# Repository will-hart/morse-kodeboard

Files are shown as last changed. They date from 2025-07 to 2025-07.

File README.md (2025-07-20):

# Morse Kodeboard

I can type 1,250 words per minute on a keyboard with only the minor side effects
of deafening people within 50 meters and wearing out the delete key inside a week.
It occurs to me that If a TKL keyboard makes me 82.24563x more of an engineer,
then how much more engineer would you become by removing 86 of the other keys?

Of course disruption requires innovation, and clearly you can't be a 1,000,000x
engineer with just an "a" key. I considered using an LLM to interpret my intentions
from the velocity and anger with which the key was pressed, but then after a
period of quiet reflection I realised training an AI to do this would immediately
make it sentient.

So to save all of humanity from an AI overlord, I instead applied my vast and
terrifying engineering skills to come up with something the likes of which
has never been seen before. This technological marvel is both simple and truly
disruptive. I invented the idea of using a sequence of long and short pulses to
represent the characters I want to type. I decided to call it a "Morse" coding
sequence, named after [Inspector Morse](https://www.imdb.com/title/tt0092379/)
because I once lived somewhere where an episode was filmed.

This new type of keyboard is clearly more than a keyboard, as without it being
a 1,000,000x engineer clearly isn't possible. So in honor of the great Inspector,
I will call this marvel of modern science a

> **Morse Kodeboard**.

## TLDR

Somehow somebody thought of this idea and I though it would be fun. This is (rust)
firmware for a RP Pico that uses a ~single button~ three buttons and morse code
and pretends to be a USB HID keyboard. Technically it doesn't have a delete button
so good luck if you morse code wrong, which is highly likely because I don't even
know morse code.

## License

* Software: MIT or Apache 2.0
* Hardware: CERN Open Hardware 2.0 - Permissive

## Things I (re/)learned while doing this

- USB Descriptors are always a pain, but I guess with embassy its kind of straightforward?
- Most embassy examples don't use tasks for USB. Its because the code is messier
  as you need to make a lot of the descriptor buffers etc `static`. Using
  `StaticCell` was pretty handy here (there was one embassy example).
- Wireshark + USBpcap are your friend! (although its still tricky working out which
  interface you're meant to look at in Windows).
  - Filter messages to a specific address using `usb.addr[0:4] == "1.1."`
- Make sure to throttle loops, this was the cause of the keyboard not being recognised
  as the USB listening loop was running without any throttling.

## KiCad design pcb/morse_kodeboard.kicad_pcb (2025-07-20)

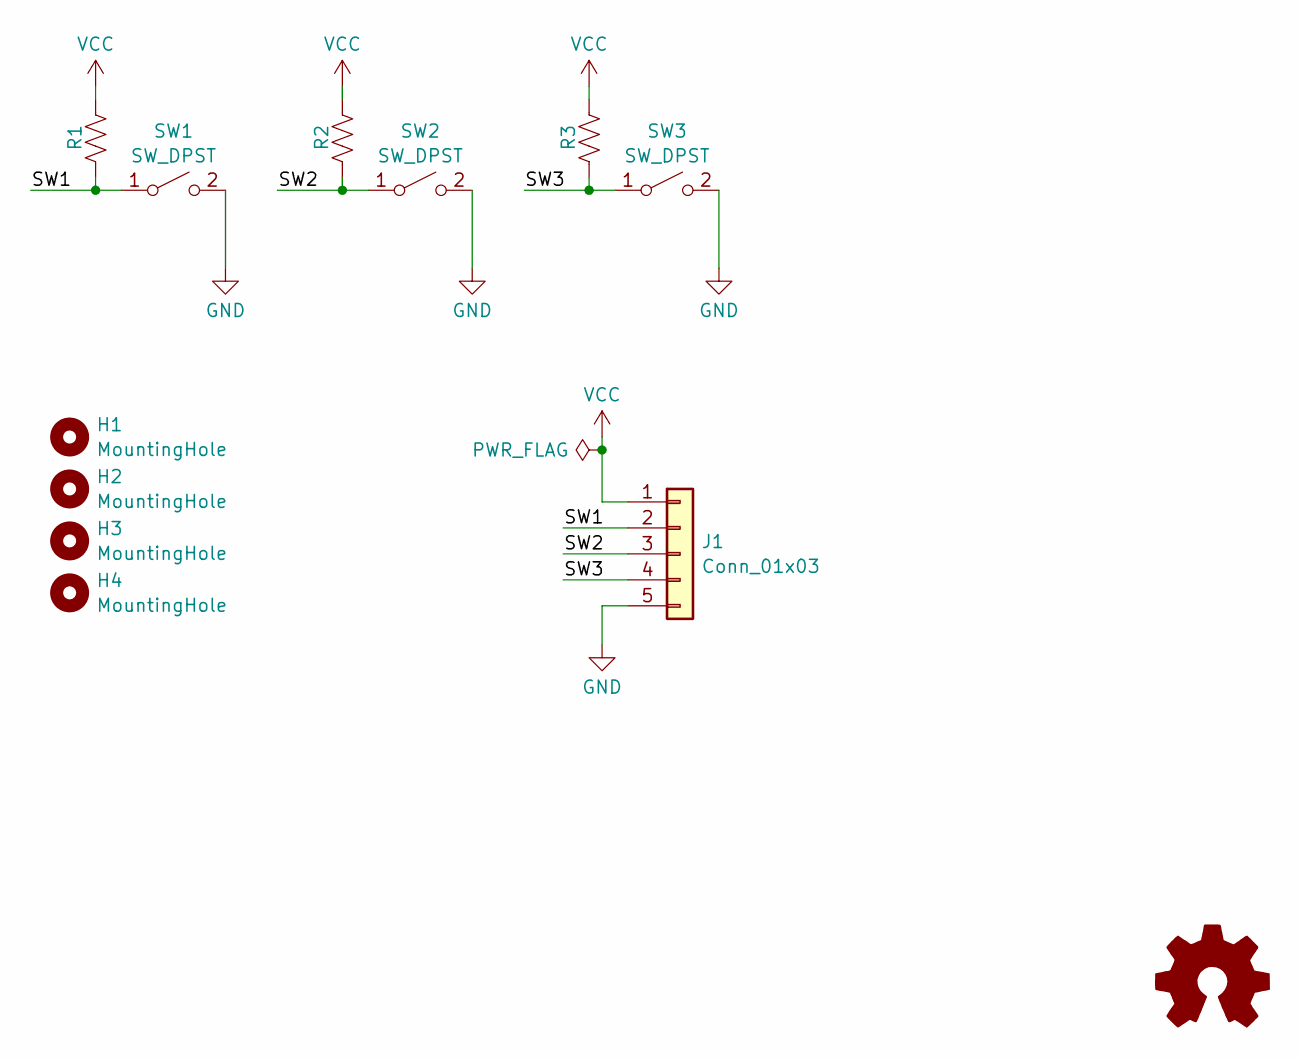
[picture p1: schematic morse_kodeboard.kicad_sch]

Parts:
H1, H2, H3, H4: MountingHole; MountingHole_2.2mm_M2
J1: Conn_01x03; JST_PH_S5B-PH-K_1x05_P2.00mm_Horizontal
R1, R2, R3: R_US; R_0805_2012Metric_Pad1.20x1.40mm_HandSolder
SW1, SW2, SW3: SW_DPST; SW_Hotswap_Kailh_MX_1.00u
SYM1: Logo_Open_Hardware_Small; OSHW-Logo2_7.3x6mm_Copper

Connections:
/SW1: J1.2, R1.2, SW1.1 (A)
/SW2: J1.3, R2.2, SW2.1 (A)
/SW3: J1.4, R3.2, SW3.1 (A)
GND: J1.5, SW1.2 (B), SW2.2 (B), SW3.2 (B)
VCC: J1.1, R1.1, R2.1, R3.1

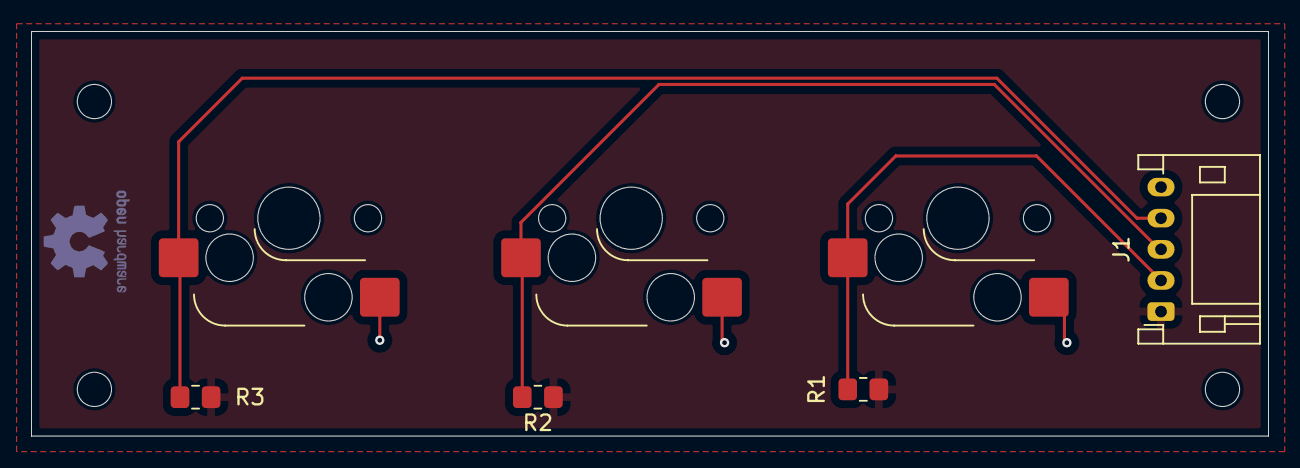
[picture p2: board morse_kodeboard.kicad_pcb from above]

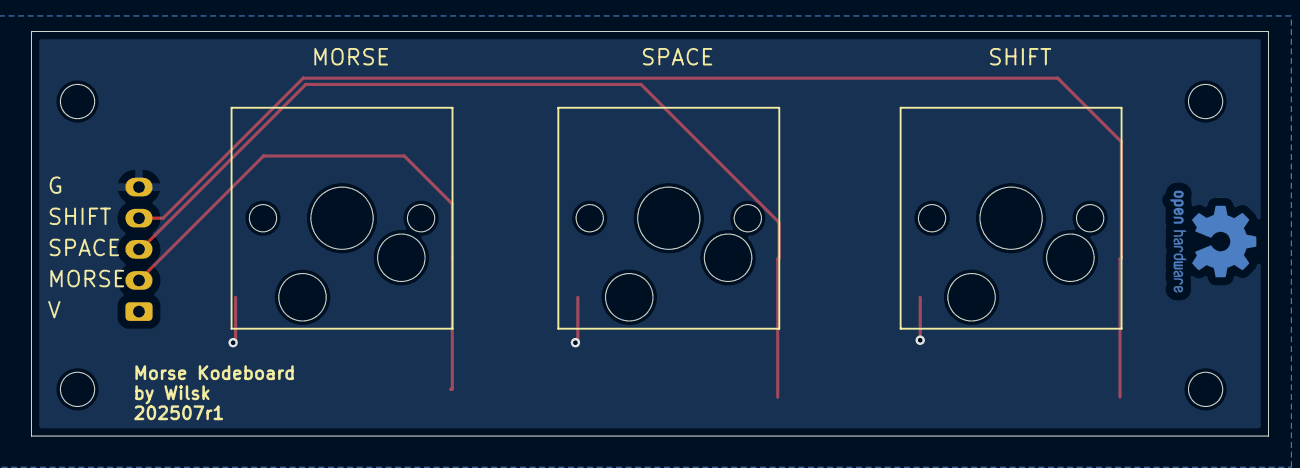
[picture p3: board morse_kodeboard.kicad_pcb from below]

Board: 2 copper layers, 79.5 x 26.0 mm, 12 parts (4 on the bottom side), 5 nets.

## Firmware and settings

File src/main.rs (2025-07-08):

#![no_std]
#![no_main]

use defmt::*;
use embassy_executor::Spawner;
use embassy_rp::bind_interrupts;
use embassy_rp::gpio::{Input, Pull};
use embassy_rp::peripherals::USB;
use embassy_rp::usb::{Driver, InterruptHandler};
use embassy_sync::blocking_mutex::raw::ThreadModeRawMutex;
use embassy_sync::channel::{Channel, Receiver, Sender};
use embassy_sync::mutex::Mutex;
use embassy_time::{Duration, Instant, Ticker, Timer};
use embassy_usb::class::hid::{HidReader, HidReaderWriter, HidWriter, State};
use embassy_usb::msos::windows_version;
use embassy_usb::{Builder, Config, UsbDevice};
use key_mapping::char_to_hid_u8;
use static_cell::StaticCell;
use usb::KodeboardUsbDeviceHandler;
use usbd_hid::descriptor::{KeyboardReport, SerializedDescriptor};
use {defmt_rtt as _, panic_probe as _};

mod debouncer;
mod decoder;
mod key_mapping;
mod usb;

bind_interrupts!(struct Irqs {
    USBCTRL_IRQ => InterruptHandler<USB>;
});

type EventChannelType = (char, bool);
type EventChannel = Channel<ThreadModeRawMutex, EventChannelType, 32>;
type EventSender = Sender<'static, ThreadModeRawMutex, EventChannelType, 32>;
type EventReceiver = Receiver<'static, ThreadModeRawMutex, EventChannelType, 32>;
static EVENT_CHANNEL: EventChannel = Channel::new();

// Descriptors for the USB. Static so we can share the USB handles around tasks
static CONFIG_DESC: StaticCell<[u8; 256]> = StaticCell::new();
static BOS_DESC: StaticCell<[u8; 256]> = StaticCell::new();
static MSOS_DESC: StaticCell<[u8; 256]> = StaticCell::new();
static CONTROL_BUF: StaticCell<[u8; 64]> = StaticCell::new();

// The state for the USB
static STATE: StaticCell<State> = StaticCell::new();

// The USB device handler
static USB_DEV_HANDLER: StaticCell<KodeboardUsbDeviceHandler> = StaticCell::new();

type ButtonType = Mutex<ThreadModeRawMutex, Option<Input<'static>>>;
static MORSE_BUTTON: ButtonType = Mutex::new(None);
static SPACE_BUTTON: ButtonType = Mutex::new(None);
static SHIFT_BUTTON: ButtonType = Mutex::new(None);

macro_rules! setup_button {
    ($pin: expr, $target: expr) => {
        // Set up the button for listening to morse code inputs
        let mut btn = Input::new($pin, Pull::Up);
        btn.set_schmitt(true);
        {
            *($target.lock().await) = Some(btn);
        }
    };
}

macro_rules! read_button {
    ($btn: expr) => {{
        let btn_unlocked = $btn.lock().await;

        if let Some(btn_ref) = btn_unlocked.as_ref() {
            Some(btn_ref.is_high())
        } else {
            None
        }
    }};
}

#[embassy_executor::main]
async fn main(spawner: Spawner) {
    info!("Connected a Morse Kodeboard!");
    info!("Configuring...");

    let p = embassy_rp::init(Default::default());

    // Set up USB
    let driver = Driver::new(p.USB, Irqs);
    let device_handler = USB_DEV_HANDLER.init(usb::KodeboardUsbDeviceHandler::default());

    // TODO: this is a test code from pid.codes, change before release
    let mut config = Config::new(0x16c0, 0x27dd);
    config.manufacturer = Some("Wilsk");
    config.product = Some("Morse Kodeboard");
    config.serial_number = Some("000001");
    config.max_power = 100;
    config.max_packet_size_0 = 64;

    let mut builder = Builder::new(
        driver,
        config,
        &mut CONFIG_DESC.init([0; 256])[..],
        &mut BOS_DESC.init([0; 256])[..],
        &mut MSOS_DESC.init([0; 256])[..],
        &mut CONTROL_BUF.init([0; 64])[..],
    );
    builder.handler(device_handler);
    builder.msos_descriptor(windows_version::WIN10, 2);

    // Create the HID inteface
    let hid_config = embassy_usb::class::hid::Config {
        report_descriptor: KeyboardReport::desc(),
        request_handler: None,
        poll_ms: 60,
        max_packet_size: 64,
    };
    let hid = HidReaderWriter::<_, 1, 8>::new(&mut builder, STATE.init(State::new()), hid_config);
    let usb = builder.build();

    // Set up the button for listening to morse code inputs
    setup_button!(p.PIN_14, SPACE_BUTTON);
    setup_button!(p.PIN_15, SHIFT_BUTTON);
    setup_button!(p.PIN_16, MORSE_BUTTON);

    info!("Configuration complete");

    // Now start spinning up the tasks
    info!("Spawning USB handling task");
    unwrap!(spawner.spawn(usb_loop(usb)));

    info!("Spawning usb HID transmission task");
    let (reader, writer) = hid.split();
    unwrap!(spawner.spawn(usb_hid_loop(EVENT_CHANNEL.receiver(), writer)));

    info!("Spawning USB request handler task");
    unwrap!(spawner.spawn(usb_request_handler(reader)));

    info!("Spawning space bar monitoring task");
    unwrap!(spawner.spawn(monitor_space_key(&SPACE_BUTTON, EVENT_CHANNEL.sender())));

    info!("Spawning morse code button observer task");
    unwrap!(spawner.spawn(generate_morse_code_characters(
        &MORSE_BUTTON,
        &SHIFT_BUTTON,
        EVENT_CHANNEL.sender()
    )));
}

/// The underlying USB send/receive loop on the [UsbDevice]
#[embassy_executor::task]
async fn usb_loop(mut usb: UsbDevice<'static, Driver<'static, USB>>) -> ! {
    usb.run().await
}

/// Listens for events from the morse code parser and sends them on as key
/// presses on the HID keyboard interface
#[embassy_executor::task]
async fn usb_hid_loop(
    event_receiver: EventReceiver,
    mut writer: HidWriter<'static, Driver<'static, USB>, 8>,
) {
    info!("Starting event loop");
    // throttle the loop a little bit
    let mut ticker = Ticker::every(Duration::from_millis(20));
    loop {
        match event_receiver.try_receive() {
            Ok((char, shift_held)) => {
                let Some(code) = char_to_hid_u8(char) else {
                    continue;
                };

                info!(
                    "Sending '{}{}' Key ({}u8)",
                    if shift_held { "shift+" } else { "" },
                    char,
                    code
                );
                let report = KeyboardReport {
                    keycodes: [code, 0, 0, 0, 0, 0],
                    leds: 0,
                    modifier: if shift_held { 0x02 } else { 0 },
                    reserved: 0,
                };
                // Send the report.
                match writer.write_serialize(&report).await {
                    Ok(()) => {}
                    Err(e) => warn!("Failed to send report: {:?}", e),
                };

                // delay 10ms before we release the key
                Timer::after(Duration::from_millis(10)).await;

                info!("Releasing '{}' Key", char);
                let report = KeyboardReport {
                    keycodes: [0, 0, 0, 0, 0, 0],
                    leds: 0,
                    modifier: 0,
                    reserved: 0,
                };
                // Send the report.
                match writer.write_serialize(&report).await {
                    Ok(()) => {}
                    Err(e) => warn!("Failed to send report: {:?}", e),
                };
            }
            Err(_err) => {
                // nop - we just move on
            }
        }

        ticker.next().await;
    }
}

/// Handles USB requests received on the [`HidReader`]
#[embassy_executor::task]
async fn usb_request_handler(reader: HidReader<'static, Driver<'static, USB>, 1>) {
    let mut request_handler = usb::KodeboardUsbRequestHandler::default();
    reader.run(false, &mut request_handler).await;
}

/// Listens for the space key and then sends a "space" event to the keyboard
#[embassy_executor::task]
async fn monitor_space_key(space_btn: &'static ButtonType, sender: EventSender) {
    let mut ticker = Ticker::every(Duration::from_millis(5));
    let mut btn_debouncer = if let Some(btn_ref) = space_btn.lock().await.as_ref() {
        debouncer::DebouncedInput::new(btn_ref.is_high())
    } else {
        crate::panic!("Unable to access button")
    };

    let mut prev_high = btn_debouncer.current();

    loop {
        let result = {
            if let Some(btn) = read_button!(space_btn) {
                btn_debouncer.debounce(btn)
            } else {
                btn_debouncer.current()
            }
        };

        if result != prev_high {
            prev_high = result;

            if result {
                info!("Space button pressed");
                sender.send((' ', false)).await;
            }
        }

        ticker.next().await;
    }
}

/// Listens to the supplied button and passes button actions (press/release) to
/// a morse code decoder. As characters are received by the encoder it sends them
/// through the [`EventSender`] channel for transmission via USB HID.
#[embassy_executor::task]
async fn generate_morse_code_characters(
    morse_btn: &'static ButtonType,
    shift_btn: &'static ButtonType,
    sender: EventSender,
) {
    info!("Configuring morse decoder");
    let mut morse_decoder = decoder::Decoder::new(60);
    let mut ticker = Ticker::every(Duration::from_millis(1));

    let mut morse_debouncer = if let Some(btn_ref) = morse_btn.lock().await.as_ref() {
        debouncer::DebouncedInput::new(btn_ref.is_high())
    } else {
        crate::panic!("Unable to configure morse button")
    };

    let mut shift_debouncer = if let Some(btn_ref) = shift_btn.lock().await.as_ref() {
        debouncer::DebouncedInput::new(btn_ref.is_high())
    } else {
        crate::panic!("Unable to configure shift button")
    };
    let mut prev_shift_state = shift_debouncer.current();
    let mut shift_held = false;

    info!("Starting morse listen loop");
    loop {
        // debounce the input
        let morse_btn = if let Some(btn) = read_button!(morse_btn) {
            morse_debouncer.debounce(btn)
        } else {
            morse_debouncer.current()
        };

        let shift_button = if let Some(btn) = read_button!(shift_btn) {
            shift_debouncer.debounce(btn)
        } else {
            shift_debouncer.current()
        };

        if shift_button != prev_shift_state {
            prev_shift_state = shift_button;
            if shift_button {
                shift_held = !shift_held;
                info!("Toggled Shift to {}", shift_held);
            }
        }

        // update the morse decoder
        let change_time = Instant::now();
        if let Some(char) = morse_decoder.push(morse_btn, change_time) {
            sender.send((char, shift_held)).await;
        }

        // only check inputs periodically
        ticker.next().await;
    }
}

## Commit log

2025-07-06 Update device details + more logging
2025-07-06 Move into tasks
    Device still not recognised, doing the usual descriptor vs me fight
2025-07-06 Throttle the USB sending loop
    This seemed to block any comms with the host PC, now it works
2025-07-06 PCB "design"
    [morse_kodeboard.kicad_pcb, morse_kodeboard.kicad_sch]
2025-07-07 Make PCB single button
    [morse_kodeboard.kicad_pcb, morse_kodeboard.kicad_sch]
2025-07-07 Update PCB files with three buttons.
    Sent off to fab as r1!
    [morse_kodeboard.kicad_pcb, morse_kodeboard.kicad_sch]
2025-07-07 Add shift button, placeholder for space
2025-07-20 Rev 1 PCB
    [morse_kodeboard.kicad_pcb]
